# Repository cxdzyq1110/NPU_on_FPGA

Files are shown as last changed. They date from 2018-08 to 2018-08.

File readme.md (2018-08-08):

# NPU设计项目
**目的** 在FPGA上面实现一个NPU计算单元。
能够执行矩阵运算（ADD / ADDi / ADDs / MULT / MULTi / DOT等）、图像处理运算（CONV / POOL等）、非线性映射（RELU / TANH / SIGM等）。  
**优点** 考虑到灵活性较强，易于修改网络结构，适用于实现小型CNN/RNN网络。  
**缺陷** 由于指令串行执行、缺少Cache导致外存读写频繁，运算性能较低。  
**联系我们** chenxudong0318@gmail.com

## projects
里面是代码和工程，选用的开发软件平台如下：
> Python 3.6.3  
> Anaconda 5.1.0  
> TensorFlow-gpu 1.3.0  
> Keras 2.1.0  
> Quartus 16.1  
> Modelsim SE 10.4

### · aFPGA
> Intel FPGA的项目工程

### · python
> python的项目工程

## 快速上手步骤
默认配置为 LeNet-5 的CNN网络，可以根据需求进行更改。  
1. 切换目录到 projects\python\keras_cnn\scripts   
2. 如果需要修改网络配置，请根据《python端代码指南.pdf》，配置《网络描述文件.txt》
> ***网络描述文件.txt***  
> I: 32, 32, 1  
> L0: C, 5, 5, 6, tanh  
> L1: S, 2, 2  
> L2: C, 5, 5, 16, tanh  
> L3: S, 2, 2  
> L4: STRIP, 400  
> L5: FC, 400, 120, tanh, dropout  
> L6: FC, 120, 84, tanh, dropout  
> L7: FC, 84, 10, sigmoid  
  
3.依次双击运行下列脚本：
> 0.创建运行环境文件夹.bat  
> 1.运行CNN训练.bat  
> 2.保存CNN模型的参数到csv文件.bat  
> 3.根据csv文件产生NPU指令CNN参数.bat  
> 4.测试CNN & 生成仿真样本.bat  
> 9.评估模型硬件化后的开销.bat

4.切换目录到 projects\python\keras_cnn\isa-npu，观察 time\_consuming.txt 文件，里面会评估整个CNN模型运算的时间、指令数量、外存读写次数。
> 运算时间 ≈ DDR读写次数 / DDR带宽  
> [estimated in 50MBps DDR bandwidth]  
> DDR-READ = 122416, DDR_WRITE=37540,   
> TOTAL-TIME=12.796480 ms,   
> TOTAL-PARA-SPACE=61706 (float number)  
> TOTAL inst number=274  

5.切换目录到 projects\aFPGA\05_modelsim  
6.修改 run.do 文件中的 #3 行，修改Quartus的安装目录
> set QUARTUS\_INSTALL\_DIR "E:/intelFPGA/16.1/quartus"  

7.修改 sim_module.bat 脚本 #2 和 #4 行，配置Altera仿真库和Modelsim的路径
> set ALTERA\_SIM\_DIR=E:\modeltech64\_10.4\altera16.1  
> set MTI\_HOME=E:\modeltech64\_10.4  

8.双击 sim_module.bat 脚本，运行仿真  
9.等待仿真结束，在spyder中运行 aFPGA\10\_python\cnn\check\_cnn.py 脚本  
10.观察使用 NPU 运算 CNN的误差
    
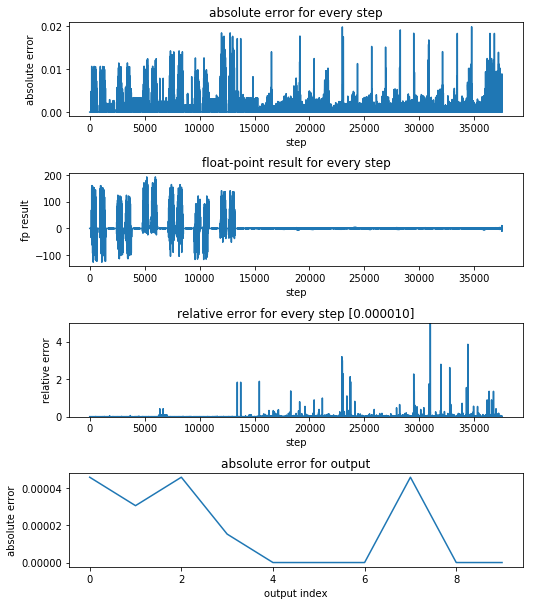
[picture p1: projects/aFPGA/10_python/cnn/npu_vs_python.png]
avatar


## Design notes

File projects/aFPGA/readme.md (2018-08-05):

# NPU项目
在FPGA上面实现一个基于NPU运算单元。  
选用DE2-115开发板，存储芯片SRAM 2MB  

## 00\_user\_logic
里面存放了各个模块的verilog逻辑代码

### · arith
> fixed_sdiv.v  
> 这是定点除法器模块，流水线型运算  
> 能够在24个clock里面完成32-bit/16-bit【Q16.16】定点除法  
> 时钟频率为100 MHz

### · cordic
> cordic\_ln.v / cordic\_rot.v / cordic\_exp\_rtl.v / cordic\_tanh\_sigm\_rtl.v  
> 考虑到之后的运算里面要大量使用 log(x) / exp(x) / sigmoid(x) 等超越函数，  
> 所以写了一个基于CORDIC的流水线型 ln(x) 函数求解器 cordic\_ln.v  
> 基于CORDIC计算的向量求模、求夹角的函数求解器 cordic\_rot.v  
> 基于CORDIC算法的 exp() 运算函数  cordic\_exp\_rtl.v  
> 也是基于 exp() 函数，再实现了 sigmoid() / tanh() 这两个函数 cordic\_tanh\_sigm\_rtl.v  
> 另外，fixed_sdiv.v 这个模块就是实现了 signed 定点数的除法运算

### · dcfifo
> dc\_fifo.v / gray\_dec\_1p.v / gray\_enc\_1p.v / sync\_dual\_clock.v  
> 这里是DCFIFO的rtl代码，使用gray码实现跨时钟域的同步

### · multiport
> mux\_ddr\_access.v  
> 这是多端口调度器

### · npu
> npu\_paras\_config.v  
> 将ROM中存放的CNN的参数配置到DDR当中去  
> npu\_inst\_join.v / npu\_inst\_excutor.v / npu\_inst\_fsm.v
> 模块 npu\_inst\_join.v 实现了将 32-bit 的短命令，拼接成 128-bit 长命令，使用超时等待机制  
> npu\_inst_excutor.v 模块则是一个 tiny版本的 ISA-NPU，缺少分支跳转的指令，但是基本的矩阵/图像运算都有  
> npu\_inst\_fsm.v 模块则是一个wrap了 ISA-NPU的模块，能够接受、缓存外部指令，并控制ISA-NPU的运算  
> npu\_conv\_rtl.v 模块，实现了**任意尺寸**的 convolution / max-pooling / mean-pooling，但是例化的时候，必须指定(Km, Kn, ATlayer)参数：Km x Kn表示最大可能的卷积/池化尺寸；ATlayer = ceil( log2( Km * Kn ) ) + 1 需要使用者提前自己计算好

### · parser
> cmd\_parser.v  
>host主机命令解析与执行器

###· ram
> dpram\_2p.v
> 双端口RAM的rtl描述

###· scfifo
> sc\_fifo.v
> 单时钟FIFO的rtl描述  
> ！注意，在标志位的生成上可能还有bug

### · sram
> sram\_controller.v  
>SRAM控制器，时序上貌似还有问题（？）

### · uart
> uart\_wr.v / uart\_rtl.v / uart\_conf.inc  
>串口读写器，可以在inc文件中配置串口的baudrate  
>而uart_wr.v模块则是在串口调度器外部接上了两个收发fifo，遵循avalon接口

## 01\_altera\_ip
调用altera提供的IP核

## 02\_testbench
测试代码
### · sram\_sim.v
> SRAM的仿真模型
### · tb\_cmd\_parser.v
> 测试cmd\_parser模块
### · tb\_cnn.v
> 测试NPU单元构建的CNN模块是否运算正确

## 03\_signaltap
使用Quartus自带的signaltap工具捕捉波形，对各个模块进行调试

## 04\_scripts
脚本，主要是mif文件，引脚绑定和时序约束文件

## 05\_modelsim
仿真文件夹，执行里面的 sim_module.bat 批处理文件即可。  
当然，要提前设置好环境变量 PATH，要包含 modelsim 的安装路径

## 08\_quartus
Quartus工程项目文件夹

## 10\_python
python脚本程序的文件夹
### *cordic文件夹*
#### · int\_cordic\_core\_generate_factor.py
> 这是生成 CORDIC_* 相关模块的ROM表初始化 mif 文件的脚本
### *npu文件夹*
#### · generate\_npu\_sram\_init_file.py
> 生成NPU测试的时候，需要对SRAM内存进行初始化
#### · check\_npu\_result.py
> 测试NPU运算的正确性，计量精度误差

### *cnn文件夹*
#### · check\_cnn.py
> 能够验证CNN运行的正确性（modelsim和python对比）、精度（浮点运算对比）
#### · generate\_npu\_inst\_paras.py
> 能够根据TF训练得到的NPU参数和NPU指令，转换成相应的mif文件，供FPGA使用

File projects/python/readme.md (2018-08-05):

# NPU项目（Python部分）
这个文件夹下面都是python代码。

## keras\_cnn
> 使用keras作为前端，tensorflow作为后端来训练基于CNN的语音识别的模型

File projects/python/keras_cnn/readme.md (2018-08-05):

# Python 相关的代码
使用keras作为前端，tensorflow作为后端来训练CNN模型

## model
存放模型参数 / tensorflow运行的中间断点数据

## scipts
存放模型配置文件 <网络描述文件.txt>  
存放各类脚本（批处理）  
0. 创建运行环境文件夹.bat  
1. 运行CNN训练.bat  
2. 保存CNN模型的参数到csv文件.bat  
3. 根据csv文件产生NPU指令CNN参数.bat  
4. 测试CNN & 生成仿真样本.bat  
5. 删除仿真样本.bat  
6. 删除CNN模型参数.bat  
7. 运行CNN推理.bat  
8. 运行tensorboard可视化.bat  
9. 评估模型硬件化后的开销.bat  
10. 生成训练样本展示文件.bat

> **使用说明**：  
> 1 首先双击运行《0. 创建运行环境文件夹.bat》创建好运行环境  
> 2 如果修改《网络描述文件.txt》，就要重新训练CNN，那么先运行《6. 删除CNN模型参数.bat》删除旧的模型，然后运行《1. 运行CNN训练.bat》  
> 3 如果要继续训练CNN，那么运行《1. 运行CNN训练.bat》  
> 4 如果仅仅是想看看CNN的推理效果，可以运行《7. 运行CNN推理.bat》  
> 5 如果想看看硬件化以后的时间/资源开销，可以运行《9. 评估模型硬件化后的开销.bat》，在../isa-npu/time\_consuming.txt中可以查看  
> 6 如果要生成FPGA硬件化的配置文件，首先运行《2. 保存CNN模型的参数到csv文件.bat》，然后运行《3. 根据csv文件--产生NPU指令 & CNN参数.bat》，就能生成NPU指令和CNN参数，并生成FPGA需要的mif文件    
> 7 如果要生成modelsim能够使用的仿真样本，运行《4. 测试CNN & 生成仿真样本.bat》；如果要删除，就运行《5. 删除仿真样本.bat》

> **关于网描述文件**：  
> 1 用“I” / “Lk" 来区分输入层和内部第k层  
> 2 对于输入层，格式为“I，H，W，Ch”，表示输入层是H高，W宽，Ch通道的输入  
> 3 对于第k层，如果是卷积层，格式就是“Lk，C，Hk，Wk，Chk, func”，其中，C表示卷积，Hk是卷积核的高，Wk是卷积核的宽，Chk是卷积层输出通道数，func是激活函数  
> 4 对于第k层，如果是池化层，格式就是“Lk，S，Hk，Wk”，其中，S表示下采样/池化，Hk是池化核的高，Wk是池化核的宽  
> 5 对于第k层，如果是压平层，格式就是“Lk，STRIP，D”，其中，STRIP表示压平，D是压平后的维度（这里需要***自行计算***，也可以写“-1”来表示自动推导）  
> 6 对于第k层，如果是全连接层，格式就是“FC，D，O, func”，其中，FC表示全连接，D是输入维度【也可以写“-1”来表示自动推导】，O是输出维度，func是激活函数  
> 7. 在每一层的结尾加上"dropout"可以开启训练时候的dropout  
> **指令数量上限为1023条，参数数量上限为64K个**

## source
存放源代码

### · train\_my\_cnn\_model.py
> 训练CNN模型参数

### · save\_parameters.py
> 保存CNN模型参数到csv文件（在para文件夹中）  

### · generate\_npu\_inst.py
> 生成NPU的指令  

###· test\_npu\_inst.py  
> 生成测试NPU的样本

### · generate\_cnn\_layers.py
> 解析网络描述文件，并且生成CNN模型

### · generate\_cnn\_layers.py
> 解析网络描述文件，并且生成CNN模型

### · load\_our\_samples.py
> 加载CNN训练/测试用的样本

### · estimate\_time\_consuming.py  
> 根据模型配置文件，评估运算时间/内存的开销

### · test\_npu\_on\_FPGA.py
> 通过串口发送NPU指令、配置CNN参数、传输测试图案到SRAM  
> 并回读CNN分类结果，与python结果进行比较，验证CNN硬件化的正确性

## test
测试用，可能tensorflow的某个功能不确定怎么用

### · test\_keras\_conv.py
> 测试卷积函数的实现过程

## para
里面存放了训练好的CNN模型参数（csv文件格式表格存储）

## samples
里面存放了语音识别的样本的展示

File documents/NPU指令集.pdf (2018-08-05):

## NPU 指令集

下面简单介绍一下 NPU 支持的指令。其中，$1 表示输入参数 1；$2 表示输入参数矩阵 2；

$3 表示输出矩阵 3；IMM 表示立即数。x 表示矩阵乘法，.x 表示矩阵点乘，*表示卷积。

助记符 | 功能 | 127:124 | 123:92 | 91:60 | 59:28 | 27:0
ADD | $3=$1+$2 | 4’B0000 | $1 地址 | $2 地址 | $3 地址 | [27:19]为矩阵行数； [18:10]为矩阵列数； [9:0]保留无用
ADDi | $3=$1+IMM | 4’B0001 | $1 地址 | IMM | $3 地址 | [27:19]为矩阵行数； [18:10]为矩阵列数； [9:0]保留无用
SUB | $3=$1-$2 | 4’B0010 | $1 地址 | $2 地址 | $3 地址 | [27:19]为矩阵行数； [18:10]为矩阵列数； [9:0]保留无用
SUBi | $3=$1-IMM | 4’B0011 | $1 地址 | IMM | $3 地址 | [27:19]为矩阵行数； [18:10]为矩阵列数； [9:0]保留无用
MULT | $3=$1x$2 | 4’B0100 | $1 地址 | $2 地址 | $3 地址 | [27:19]为矩阵 1 行数； [18:10]为矩阵 1 列数； [9:1]为矩阵 2 列数； [0]保留无用
MULTi | $3=$1xIMM | 4’B0101 | $1 地址 | IMM | $3 地址 | [27:19]为矩阵行数； [18:10]为矩阵列数； [9:0]保留无用
DOT | $3=$1.x$2 | 4’B0110 | $1 地址 | $2 地址 | $3 地址 | [27:19]为矩阵行数； [18:10]为矩阵列数； [9:0]保留无用
TRAN | $3=($1)’ 矩阵转置 | 4’B1101 | $1 地址 | 保留 | $3 地址 | [27:19]为矩阵 1 行数； [18:10]为矩阵 1 列数
CONV | $3=$1*$2 $1 为图像 $2 为卷积核 | 4’B0111 | $1 地址 | $2 地址 | $3 地址 | [27:19]为矩阵 1 行数； [18:10]为矩阵 1 列数； [9:5]为矩阵 2 行数； [4:0]为矩阵 2 列数

助记符 | 功能 | 127:124 | 123:92 | 91:60 | 59:28 | 27:0
POOL | $3=down($1) 下采样操作 | 4’B1000 | $1 地址 | MODE 0: max 1: mean | $3 地址 | [27:19]为矩阵 1 行数； [18:10]为矩阵 1 列数； [9:5]为矩阵 2 行数； [4:0]为矩阵 2 列数
SIGM | $3=sigm($1) | 4’B1001 | $1 地址 | 保留 | $3 地址 | [27:19]为矩阵 1 行数； [18:10]为矩阵 1 列数
RELU | $3=relu($1) | 4’B1010 | $1 地址 | 保留 | $3 地址 | [27:19]为矩阵 1 行数； [18:10]为矩阵 1 列数
TANH | $3=tanh($1) | 4’B1011 | $1 地址 | 保留 | $3 地址 | [27:19]为矩阵 1 行数； [18:10]为矩阵 1 列数
GRAY | $3=gray($1) | 4’B1100 | $1 地址 RGB565 | 保留 | $3 地址 YCbCr | [27:19]为矩阵 1 行数； [18:10]为矩阵 1 列数

为了实现对 NPU 单元运算启动和运算结束的控制，扩展支持了如下控制指令：

助记符 | 指令值 | 指令说明
NOP | 128’D0 空操作 | 一旦 NPU 在指令 RAM 中寻址到了 NOP 操作，说明 RAM 里面该执行的指令都完成了
RESET | 128’D1 复位 RAM | 表示要重新定制指令 RAM 里面的内容
START | 128’D2 启动运算 | 表示 NPU 要启动 RAM 里指令的运行

PS: 为了 NPU 实现的方便，这里不限定 CONV 卷积运算中卷积核尺寸；POOL 池化运算中，

池化核尺寸也没有限定。但是所有矩阵操作都必须满足矩阵大小在 511 x 511 以内。尽管损失

了一些灵活性，但是系统结构变得十分的简单。

另外，卷积、池化的实现，依赖于 npu_conv_rtl 模块，这里有参数 Km/Kn，CNN 设计中的

卷积/池化尺寸必须在(Km, Kn)内。只要(1,1) ~ (Km, Kn)内任意尺寸都可以

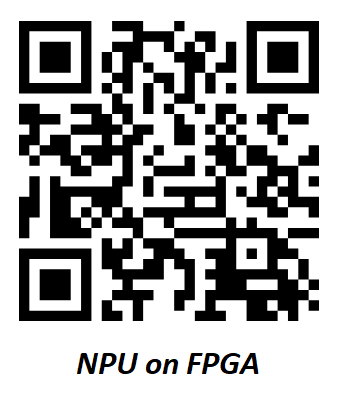
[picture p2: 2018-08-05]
QR/qr_github_npu_on_fpga.png

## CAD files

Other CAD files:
projects/aFPGA/03_signaltap/sram_controller.stp
projects/aFPGA/03_signaltap/cmd_parser.stp

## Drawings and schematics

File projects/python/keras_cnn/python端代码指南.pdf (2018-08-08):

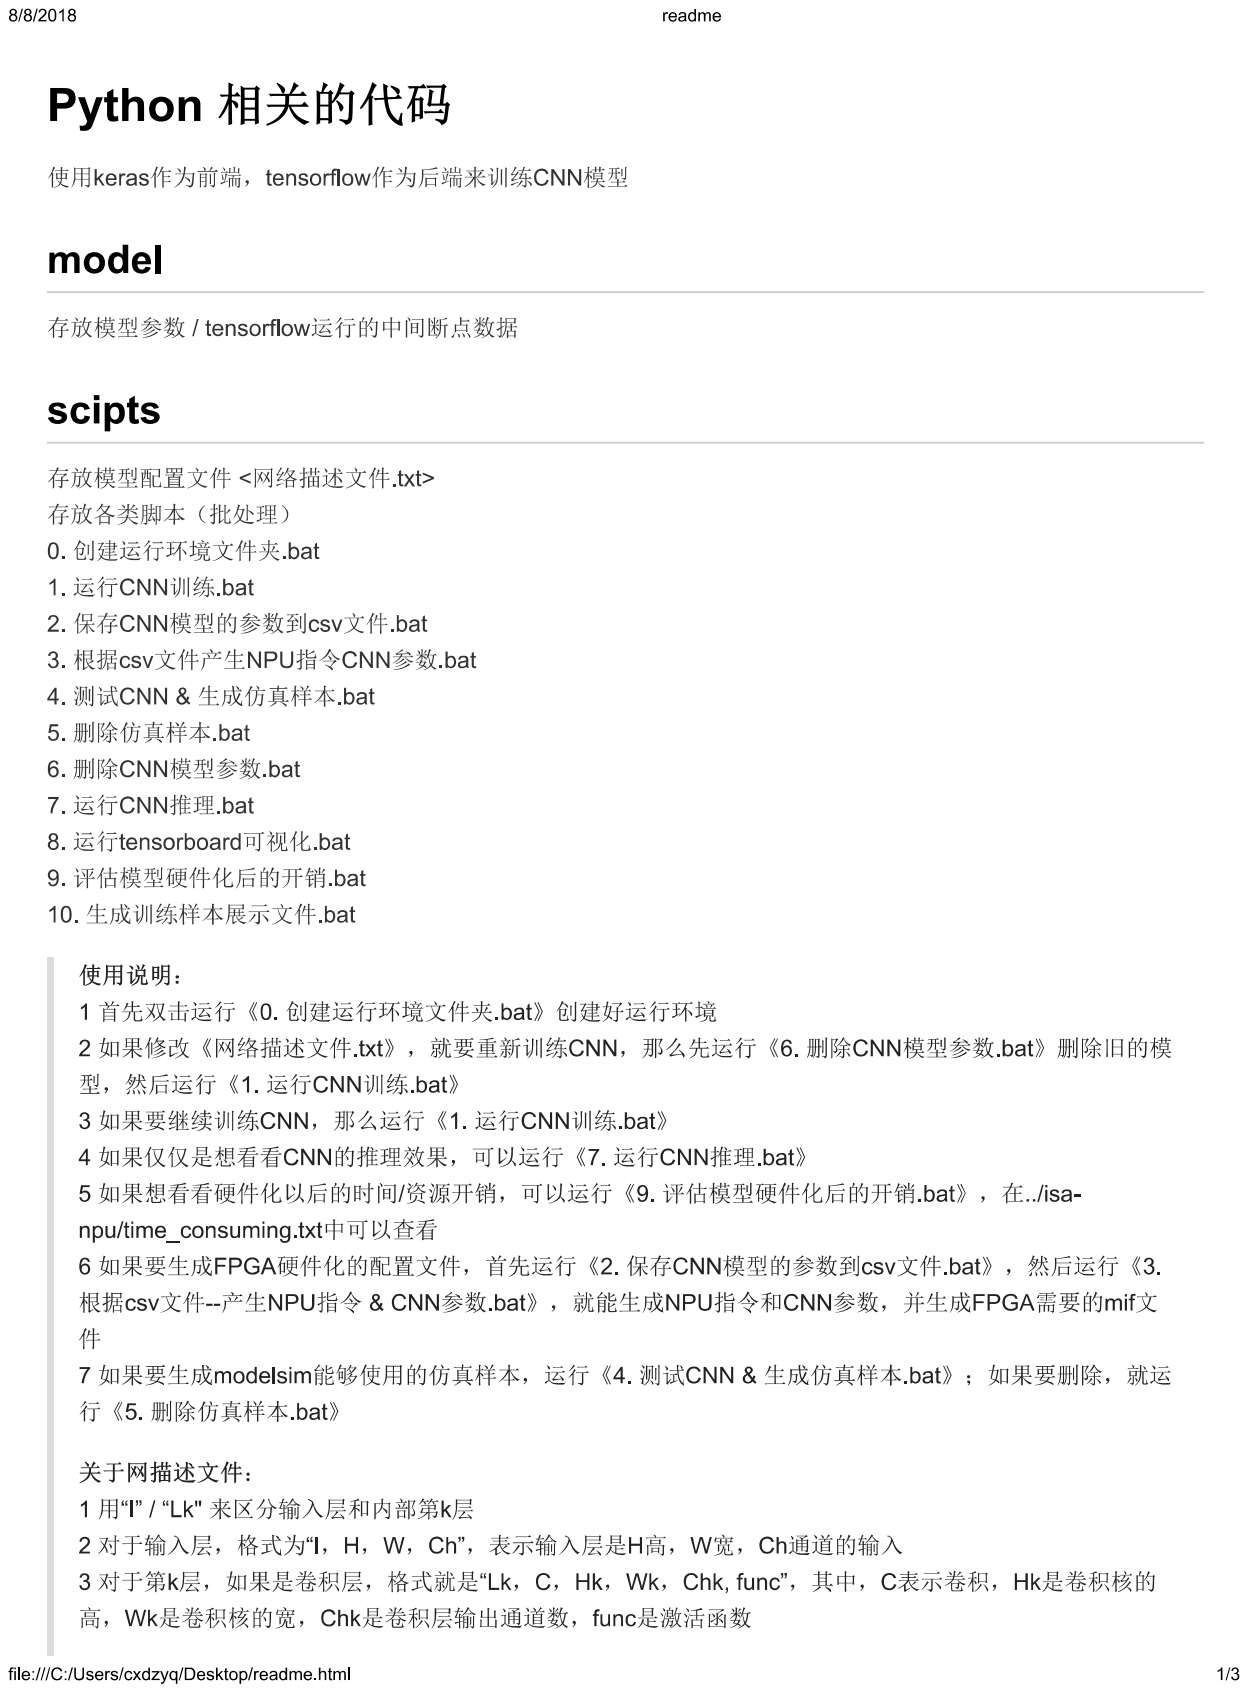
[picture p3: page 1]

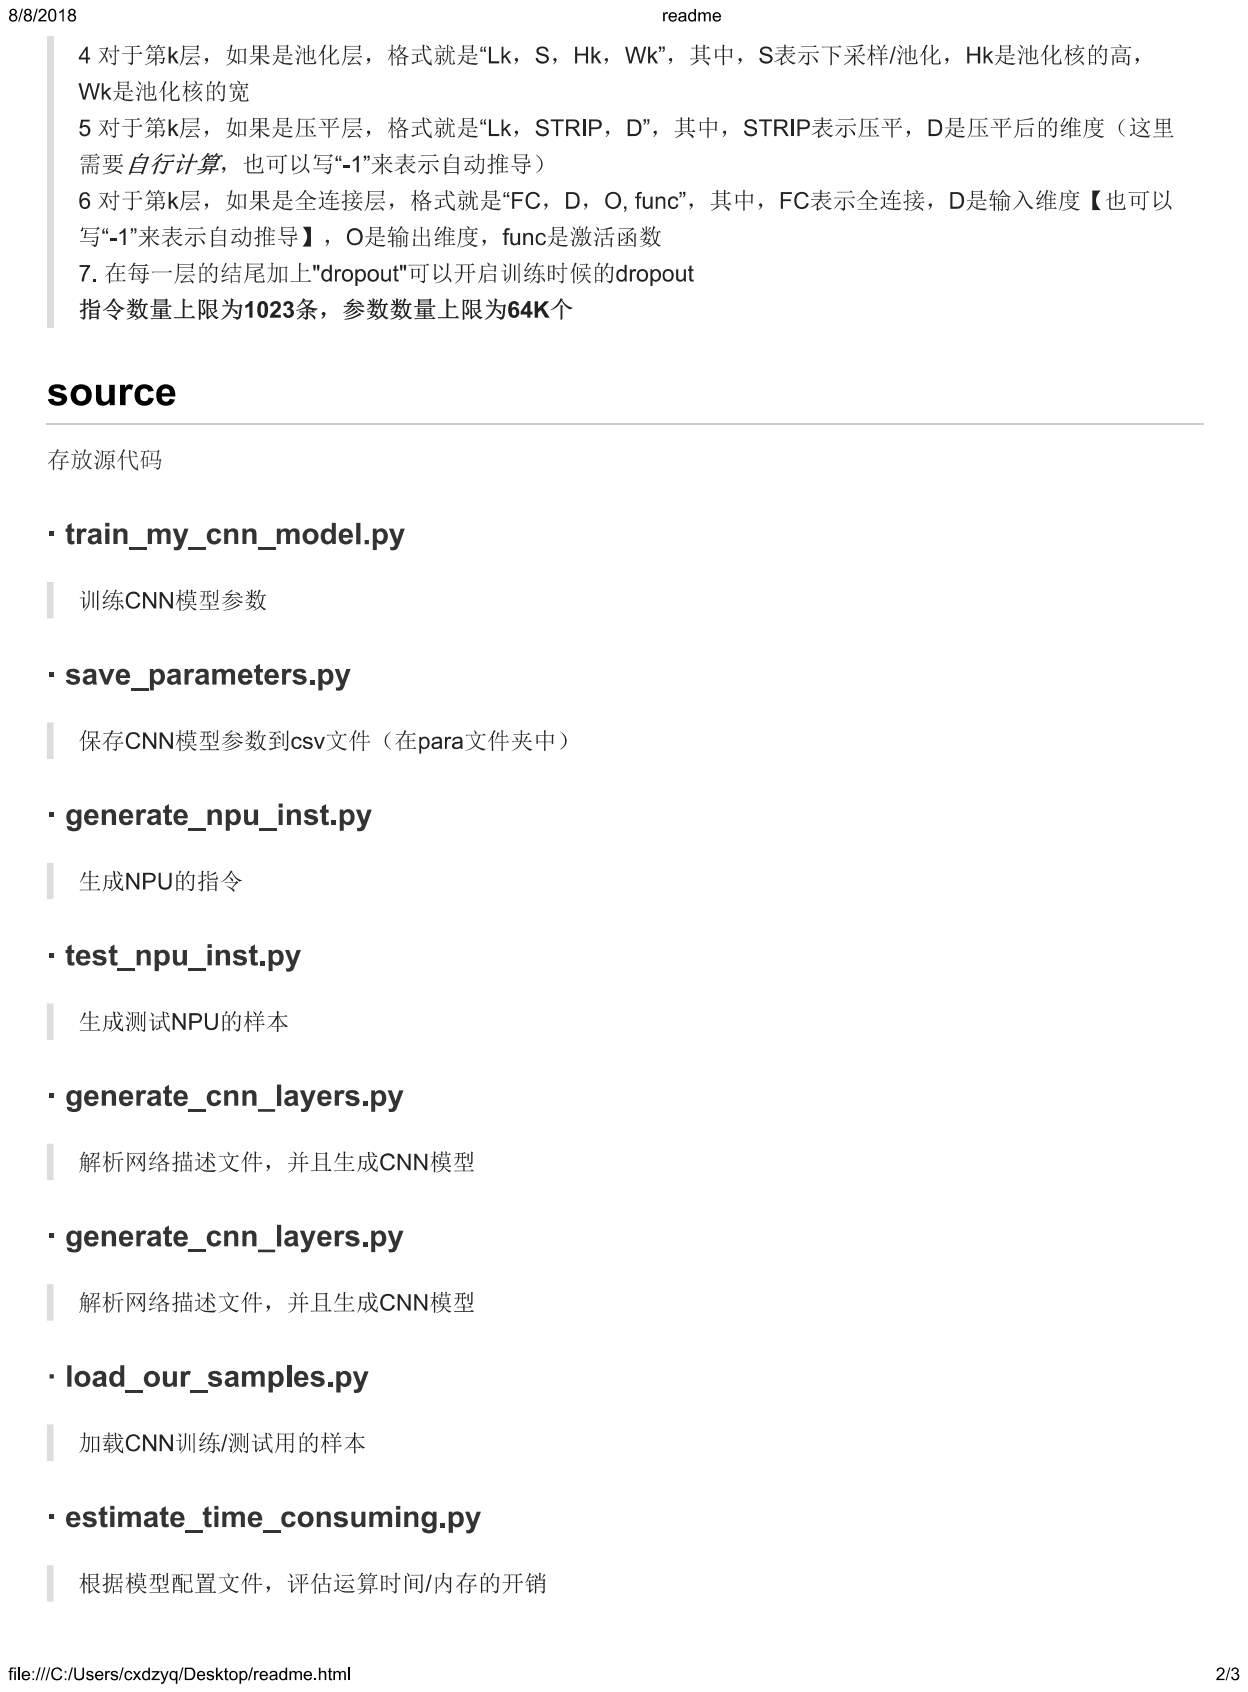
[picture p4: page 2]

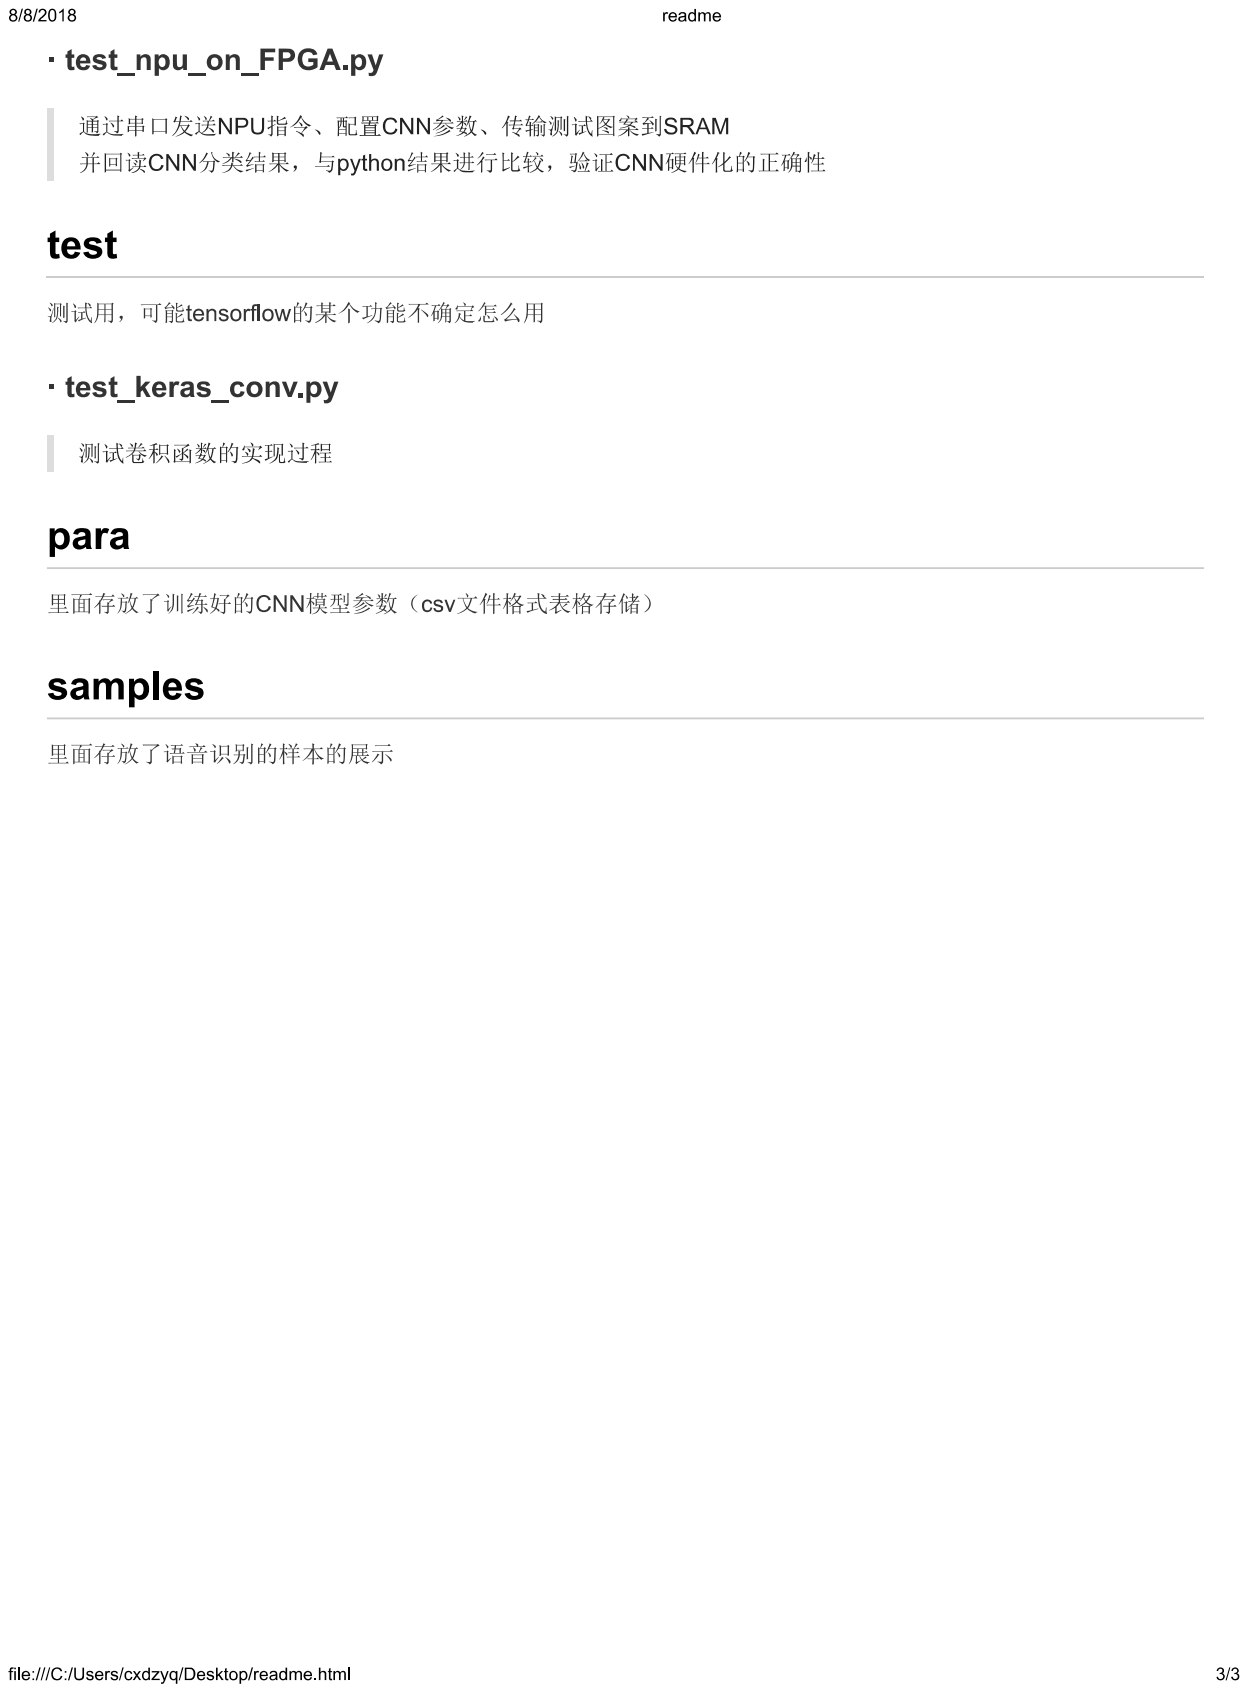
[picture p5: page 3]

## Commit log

2018-08-05 创建一个NPU的项目工程，目标： 1. 实现一个简单的lenet 2. 能够处理mnist手写数字识别
    [cmd_parser.stp, sram_controller.stp]
2018-08-05 :sparkles: 增加了Lenet-5的实现，并在mnist手写数字集上进行训练/测试
2018-08-05 :memo: 上传NPU指令集说明文档
2018-08-05 :memo: 修正了FPGA相关的readme.md
2018-08-08 :memo: 添加了快速上手的步骤说明
2018-08-08 :memo: 补充了NPU计算CNN的时间开销评估的说明
2018-08-08 :bug: 修正了公式不能显示的问题
2018-08-16 看了一下Quartus综合后的tech view，确认npu_conv_rtl中的generate-endgenerate确实可以使用（可综合）
